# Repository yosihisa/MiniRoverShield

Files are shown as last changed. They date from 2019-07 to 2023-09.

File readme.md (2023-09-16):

# Cansat Shield for Arduino Nano 33  
Arduino Nano 33 BLE Sense用のCanSatシールドです。    
これを使うことにより、簡単に小型ローバーを作ることができるようになります。  

# 搭載している機能  
標準的なCanSatに必要な以下の機能を搭載しています。  
・モーター  
・モータードライバ2つ  
・電池(Li-ion 10440)  
・電源回路  
・GNSSモジュール  
・microSD(データ記録用)  
・ニクロム線(パラシュート分離用)  
・MCU (Arduino nano 33内蔵)  
・地磁気センサ(Arduino nano 33内蔵)  
・通信機(Arduino nano 33内蔵)  

# 使い方
## 開発環境 
Arduino IDEを使用します。  
Arduino Nano 33 BLE Senseを使えるようにするためにいくつかのライブラリをインストールする必要があります。

1. Arduino IDEのボードマネージャで「Nano 33 BLE」と検索して「Arduino Mbed OS Nano Boards」をインストールします。
1. Arduino IDEのライブラリマネージャで「Nano 33 BLE」と検索して以下のライブラリをインストールします。 
  - **ArduinoBLE** (BLE通信用)
  - **Arduino_APDS9960** (ジェスチャ,明るさ,近接センサ用)
  - **Arduino_HTS221** (温度,湿度センサ用)
  - **Arduino_LPS22HB** (気圧センサ用)
  - **Arduino_LSM9DS1** (9軸センサ用)
## 動作確認
Arduino Nano 33 BLE Senseに搭載されているセンサの動作確認は各ライブラリのsample sketchを使用してください。  
MiniRoverShieldの動作確認は `/sketch` 以下の`test_`から始まるsketchを使用してください。

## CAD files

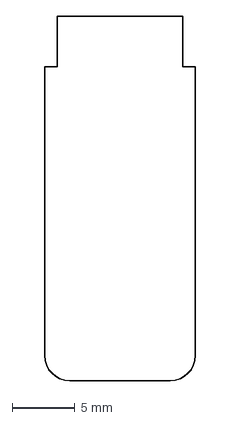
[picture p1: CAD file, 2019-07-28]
PCB/Edge_LED.dxf
12.0 x 29.0 mm

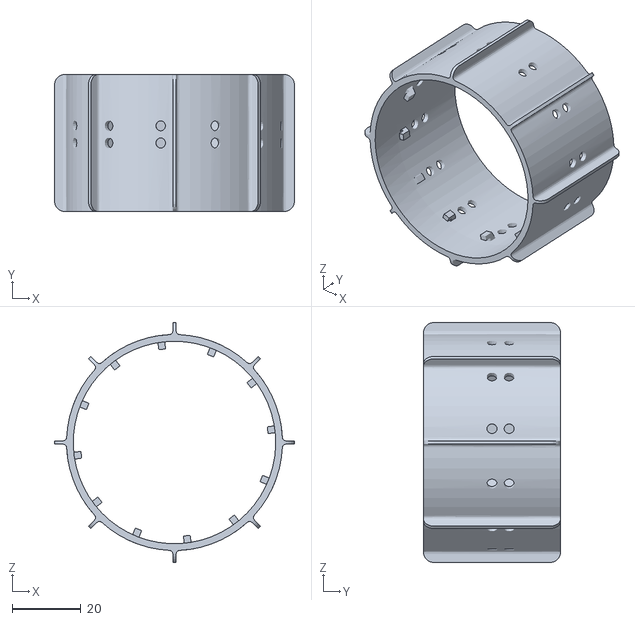
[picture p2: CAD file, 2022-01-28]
STL/Tire.stl
70.0 x 40.0 x 70.0

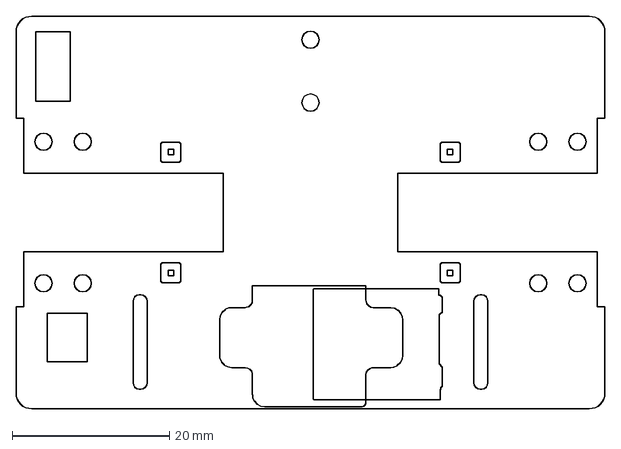
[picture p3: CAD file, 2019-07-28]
PCB/Edge.dxf
75.0 x 50.0 mm

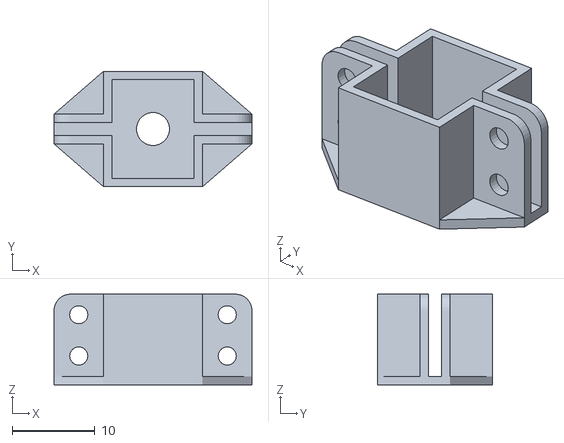
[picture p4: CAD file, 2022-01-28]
STL/TailFixture.stl
24.0 x 14.0 x 11.0

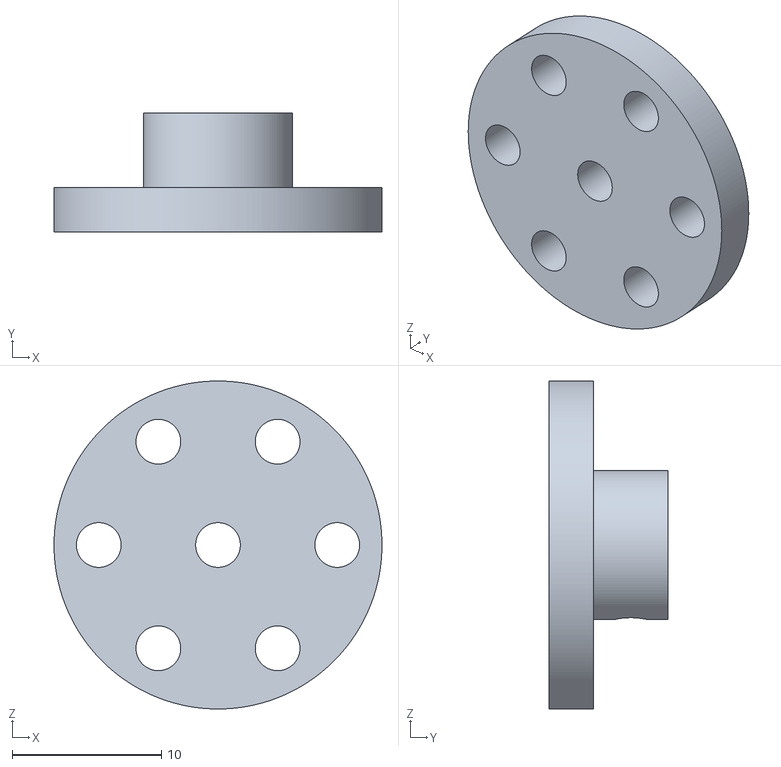
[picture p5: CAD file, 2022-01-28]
STL/Hub.stl
22.0 x 8.00 x 22.0

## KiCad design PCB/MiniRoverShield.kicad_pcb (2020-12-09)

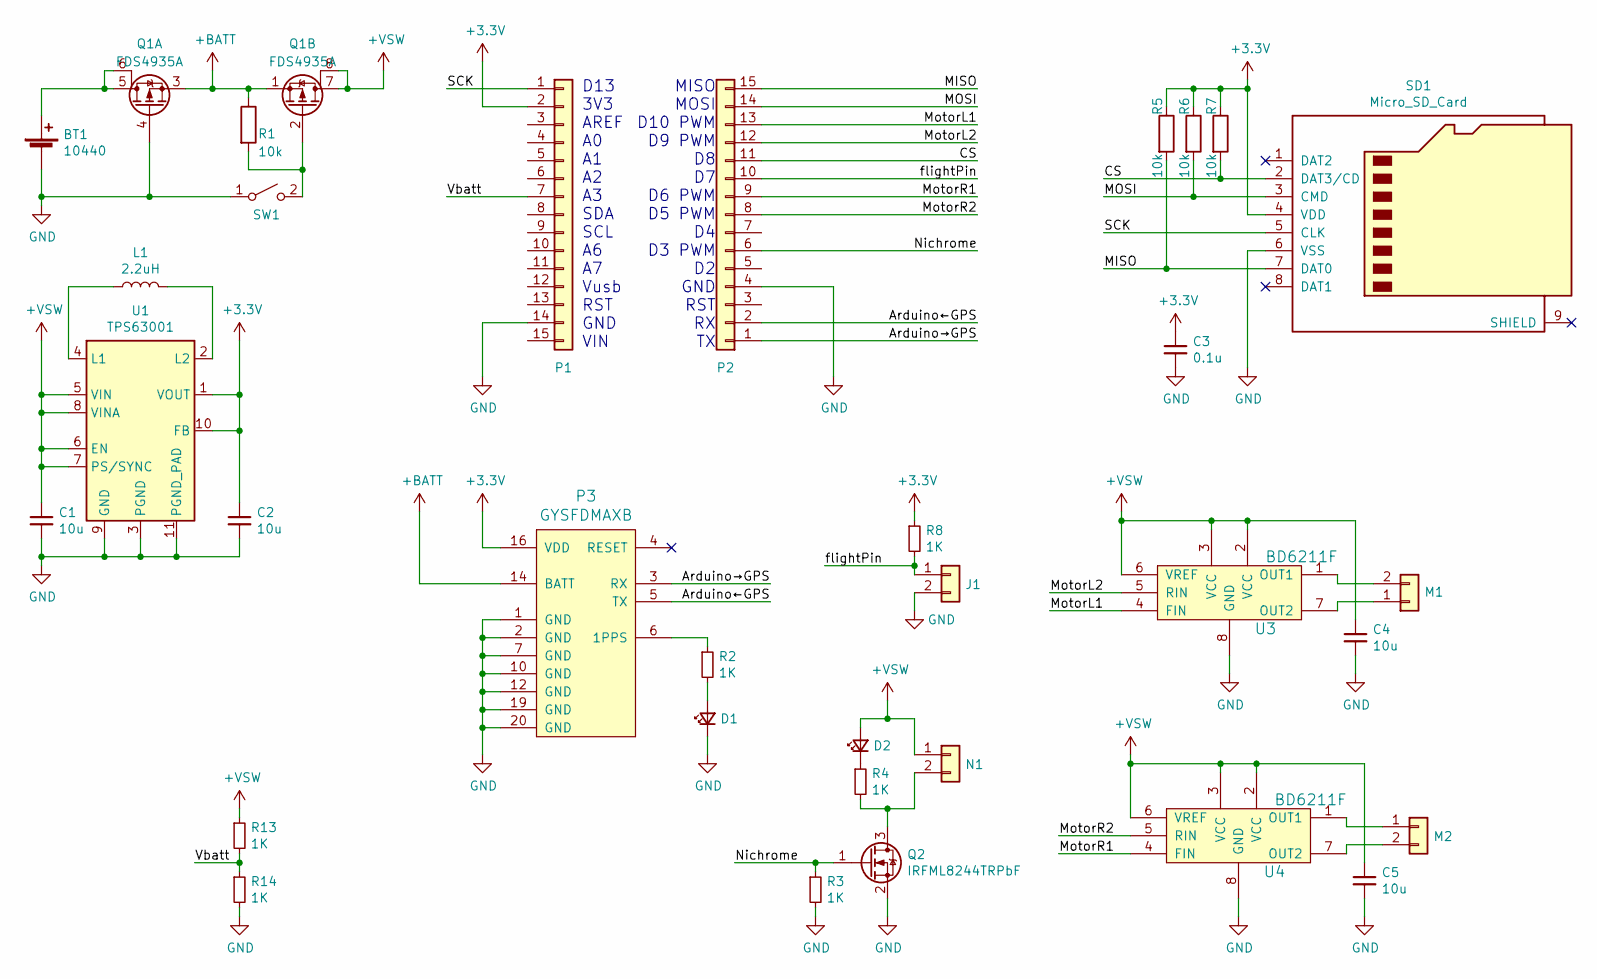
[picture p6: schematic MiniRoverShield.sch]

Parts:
BT1: 10440; BC-0402_AAA
C1, C2, C4, C5: 10u; C_0805_2012Metric_Pad1.15x1.40mm_HandSolder
C3: 0.1u; C_0603_1608Metric_Pad1.05x0.95mm_HandSolder
D1, D2: RED; LED_0603_1608Metric_Castellated
J1: flightPin; PinHeader_1x02_P2.54mm_Horizontal
L1: 2.2uH; TDK_VLS3012
M1, M2: Motor; JST_EH_B02B-EH-A_1x02_P2.50mm_Vertical
N1: Nichrome; MPT0.5_2-2.54
P1, P2: Arduino nano 33; PinSocket_1x15_P2.54mm_Vertical
P3: GYSFDMAXB
Q1: FDS4935A; SOIC-8_3.9x4.9mm_P1.27mm
Q2: IRFML8244TRPbF; SOT-23
R1, R5, R6, R7: 10k; R_0603_1608Metric_Pad1.05x0.95mm_HandSolder
R2, R3, R4, R8, R13, R14: 1K; R_0603_1608Metric_Pad1.05x0.95mm_HandSolder
SD1: Micro_SD_Card; microSD_HC_Hirose_DM3AT-SF-PEJM5
SW1: Power; SS-12D01-VG4
U1: TPS63001; Texas_S-PVSON-N10_ThermalVias
U3, U4: BD6211F; SOIC-8_3.9x4.9mm_P1.27mm

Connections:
+3V3: C2.1, C3.1, P1.2, P3.16 (VDD), R5.1, R6.1, R7.1, R8.1, SD1.4 (VDD), U1.1 (VOUT), U1.10 (FB)
+BATT: P3.14 (BATT), Q1.1 (S), Q1.3 (S), R1.1
+VSW: C1.1, C4.1, C5.1, D2.2 (A), N1.1, Q1.7 (D), Q1.8 (D), R13.1, U1.5 (VIN), U1.6 (EN), U1.7 (PS/SYNC), U1.8 (VINA), U3.2 (VCC), U3.3 (VCC), U3.6 (VREF), U4.2 (VCC), U4.3 (VCC), U4.6 (VREF)
/Arduino←GPS: P2.2, P3.5 (TX)
/Arduino→GPS: P2.1, P3.3 (RX)
/CS: P2.11, R7.2, SD1.2 (DAT3/CD)
/MISO: P2.15, R5.2, SD1.7 (DAT0)
/MOSI: P2.14, R6.2, SD1.3 (CMD)
/MotorL1: P2.13, U3.4 (FIN)
/MotorL2: P2.12, U3.5 (RIN)
/MotorR1: P2.9, U4.4 (FIN)
/MotorR2: P2.8, U4.5 (RIN)
/Nichrome: P2.6, Q2.1 (G), R3.1
/SCK: P1.1, SD1.5 (CLK)
/Vbatt: P1.7, R13.2, R14.1
/flightPin: J1.1, P2.10, R8.2
GND: BT1.2 (-), C1.2, C2.2, C3.2, C4.2, C5.2, D1.1 (K), J1.2, P1.14, P2.4, P3.1 (GND), P3.2 (GND), P3.7 (GND), P3.10 (GND), P3.12 (GND), P3.19 (GND), P3.20 (GND), Q1.4 (G), Q2.2 (S), R3.2, R14.2, SD1.6 (VSS), SW1.1 (A), U1.3 (PGND), U1.9 (GND), U1.11 (PGND_PAD), U3.8 (GND), U4.8 (GND)
unnamed: BT1.1 (+), Q1.5 (D), Q1.6 (D)
unnamed: D1.2 (A), R2.2
unnamed: D2.1 (K), R4.1
unnamed: L1.1, U1.4 (L1)
unnamed: L1.2, U1.2 (L2)
unnamed: M1.1, U3.7 (OUT2)
unnamed: M1.2, U3.1 (OUT1)
unnamed: M2.1, U4.1 (OUT1)
unnamed: M2.2, U4.7 (OUT2)
unnamed: N1.2, Q2.3 (D), R4.2
unnamed: P3.6 (1PPS), R2.1
unnamed: Q1.2 (4G), R1.2, SW1.2 (B)

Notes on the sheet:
D13 3V3 AREF A0 A1 A2 A3 SDA SCL A6 A7 Vusb RST GND VIN
MISO MOSI D10 PWM D9 PWM D8 D7 D6 PWM D5 PWM D4 D3 PWM D2 GND RST RX TX

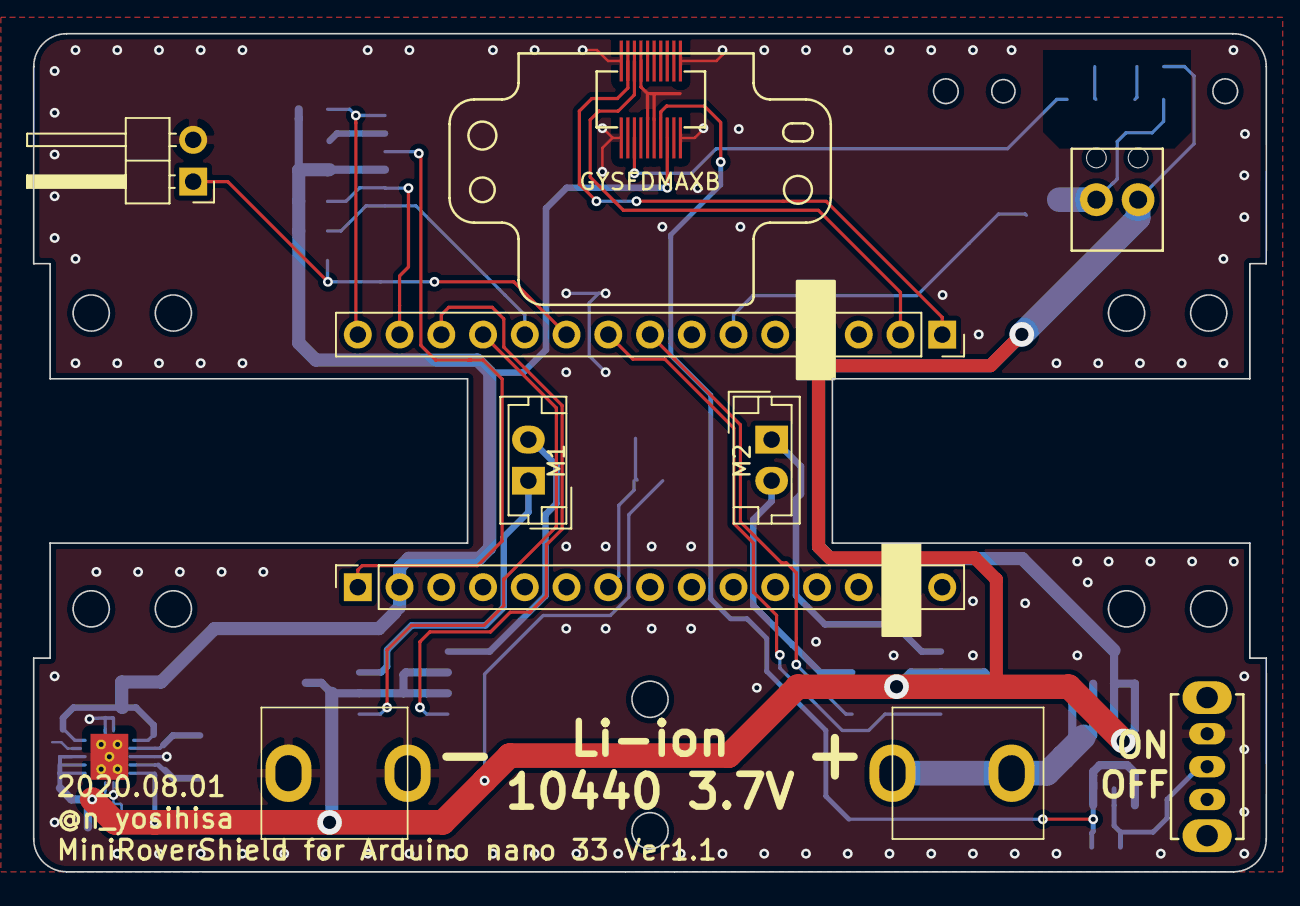
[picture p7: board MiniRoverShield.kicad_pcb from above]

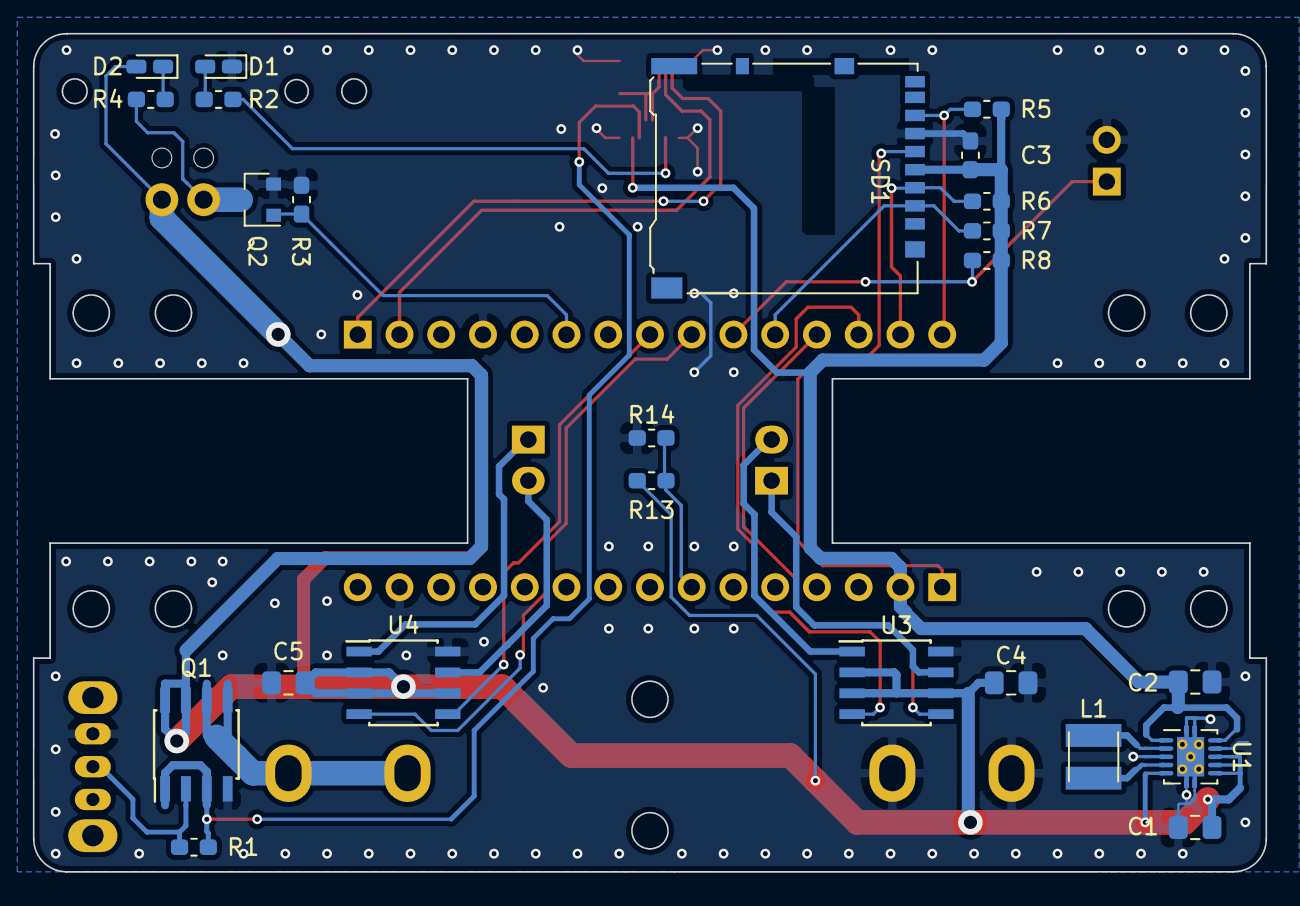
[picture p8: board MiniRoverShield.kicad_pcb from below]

Board: 2 copper layers, 75.0 x 51.0 mm, 33 parts (24 on the bottom side), 29 nets.

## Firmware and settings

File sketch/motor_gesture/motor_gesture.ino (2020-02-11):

#include <Arduino_APDS9960.h>

#define MOTOR_LF  10
#define MOTOR_LR  9
#define MOTOR_RF  6
#define MOTOR_RR  5

int proximity;
int i;
void setup() {
  Serial.begin(9600);

  APDS.begin();

  i = 0;
}


void loop() {

  if (APDS.gestureAvailable()) {
    int gesture = APDS.readGesture();
    int pwm = 255 ;
    switch (gesture) {

      case GESTURE_LEFT: //前
        motor(pwm, pwm);
        delay(300);
        break;
      case GESTURE_UP: //右
        motor(pwm, 0);
        delay(300);
        break;

      case GESTURE_DOWN: //左
        motor(0, pwm);
        delay(300);
        break;

      case GESTURE_RIGHT: //後
        motor(-pwm, -pwm);
        delay(50);
        break;

      default:
        break;
    }

    motor(0, 0);
  }

  if (i % 3 == 0) {
    digitalWrite(LEDR, HIGH);
    digitalWrite(LEDG, LOW);
    digitalWrite(LEDB, HIGH);
  }
  if (i % 3 == 1) {
    digitalWrite(LEDR, HIGH);
    digitalWrite(LEDG, HIGH);
    digitalWrite(LEDB, LOW);
  }
  if (i % 3 == 2) {
    digitalWrite(LEDR, LOW);
    digitalWrite(LEDG, HIGH);
    digitalWrite(LEDB, HIGH);
  }

  i++;

}

void motor(int L , int R) {
  if (L >= 0) {
    analogWrite(MOTOR_LF, L);
    analogWrite(MOTOR_LR, 0);
  } else {
    analogWrite(MOTOR_LF, 0);
    analogWrite(MOTOR_LR, -L);
  }

  if (R >= 0) {
    analogWrite(MOTOR_RF, R);
    analogWrite(MOTOR_RR, 0);
  } else {
    analogWrite(MOTOR_RF, 0);
    analogWrite(MOTOR_RR, -R);
  }
}

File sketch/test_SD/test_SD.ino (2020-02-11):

#include <SPI.h>
#include <SD.h>

Sd2Card card;
SdVolume volume;
SdFile root;

const int chipSelect = 8;

void setup() {
  // Open serial communications and wait for port to open:
  Serial.begin(115200);
  while (!Serial) {
    ; // wait for serial port to connect. Needed for native USB port only
  }

  Serial.print("\nInitializing SD card...");

  // we'll use the initialization code from the utility libraries
  // since we're just testing if the card is working!
  if (!card.init(SPI_HALF_SPEED, chipSelect)) {
    Serial.println("initialization failed. Things to check:");
    Serial.println("* is a card inserted?");
    Serial.println("* is your wiring correct?");
    Serial.println("* did you change the chipSelect pin to match your shield or module?");
    while (1);
  } else {
    Serial.println("Wiring is correct and a card is present.");
  }

  // print the type of card
  Serial.println();
  Serial.print("Card type:         ");
  switch (card.type()) {
    case SD_CARD_TYPE_SD1:
      Serial.println("SD1");
      break;
    case SD_CARD_TYPE_SD2:
      Serial.println("SD2");
      break;
    case SD_CARD_TYPE_SDHC:
      Serial.println("SDHC");
      break;
    default:
      Serial.println("Unknown");
  }

  // Now we will try to open the 'volume'/'partition' - it should be FAT16 or FAT32
  if (!volume.init(card)) {
    Serial.println("Could not find FAT16/FAT32 partition.\nMake sure you've formatted the card");
    while (1);
  }

  Serial.print("Clusters:          ");
  Serial.println(volume.clusterCount());
  Serial.print("Blocks x Cluster:  ");
  Serial.println(volume.blocksPerCluster());

  Serial.print("Total Blocks:      ");
  Serial.println(volume.blocksPerCluster() * volume.clusterCount());
  Serial.println();

  // print the type and size of the first FAT-type volume
  uint32_t volumesize;
  Serial.print("Volume type is:    FAT");
  Serial.println(volume.fatType(), DEC);

  volumesize = volume.blocksPerCluster();    // clusters are collections of blocks
  volumesize *= volume.clusterCount();       // we'll have a lot of clusters
  volumesize /= 2;                           // SD card blocks are always 512 bytes (2 blocks are 1KB)
  Serial.print("Volume size (Kb):  ");
  Serial.println(volumesize);
  Serial.print("Volume size (Mb):  ");
  volumesize /= 1024;
  Serial.println(volumesize);
  Serial.print("Volume size (Gb):  ");
  Serial.println((float)volumesize / 1024.0);

  Serial.println("\nFiles found on the card (name, date and size in bytes): ");
  root.openRoot(volume);

  // list all files in the card with date and size
  root.ls(LS_R | LS_DATE | LS_SIZE);
}

void loop(void) {
}

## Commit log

2019-07-28 Add PCB
    回路図作成
    基板 外形と部品配置まで
    [Edge.dxf, Edge_LED.dxf, MiniRoverShield.kicad_pcb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]
2019-08-03 配線完了
    [MiniRoverShield.kicad_pcb, MiniRoverShield.sch]
2019-08-03 Add Silk
    [MiniRoverShield.kicad_pcb]
2019-08-03 Add Gerber
    [MiniRoverShield-B.Cu.gbl, MiniRoverShield-B.Mask.gbs, MiniRoverShield-B.SilkS.gbo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]
2020-02-11 Remove Line Trace
    [MiniRoverShield.kicad_pcb, MiniRoverShield.sch]
2020-02-21 Gerber Update
    [MiniRoverShield-B.Cu.gbl, MiniRoverShield-B.Mask.gbs, MiniRoverShield-B.SilkS.gbo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]
2020-07-31 Change inductor
    VLF4012AT-2R2をVLS3012HBX-2R2Mに変更
    [MiniRoverShield-B.Cu.gbl, MiniRoverShield-B.Mask.gbs, MiniRoverShield-B.SilkS.gbo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]
2020-12-09 FET裏のパターン修正
    [MiniRoverShield.kicad_pcb]
2020-12-09 コメント追加
2022-01-28 Add STL files
    [Hub.stl, TailFixture.stl, Tire.stl]
